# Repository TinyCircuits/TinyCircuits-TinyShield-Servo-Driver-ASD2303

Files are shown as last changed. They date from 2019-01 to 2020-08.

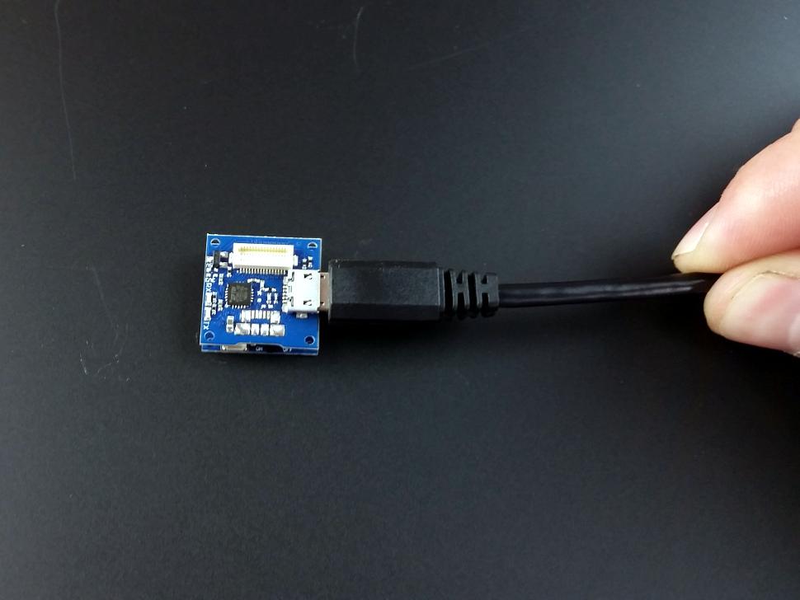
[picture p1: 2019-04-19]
images/ASD2303-Tutorial-Image-03.png

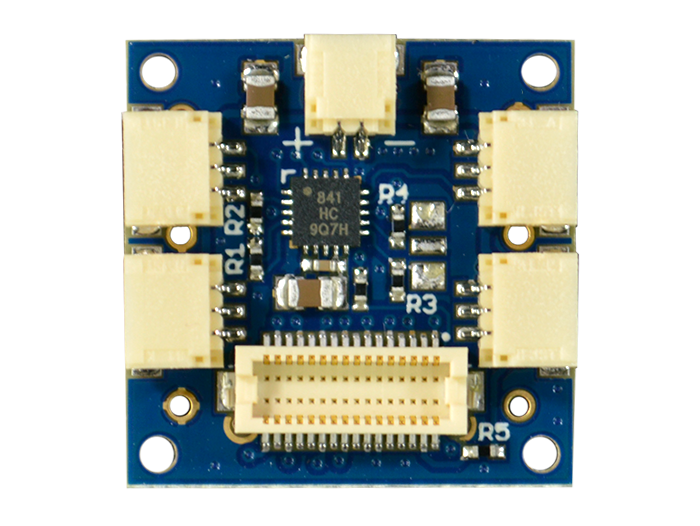
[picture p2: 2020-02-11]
images/ASD2303-R-Tutorial-Image-01.png

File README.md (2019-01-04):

# TinyCircuits-TinyShield-Servo-Driver-ASD2303
# ASD2303 Rev3

These are the design files for the TinyCircuits ASD2021 Rev 3 PCB.  This is a TinyShield (Square Version, 20mm x 20mm) that can drive up to four servos at a time.  

Format is in Cadsoft Eagle format - Eagle version 6.2 was used for the original design.

For more infomation on this, check out the product page at TinyCircuits.com:  https://tinycircuits.com/collections/motors/products/servo-tinyshield

# License:

Design by TinyCircuits.
All design files are released under the Creative Commons Attribution Share-Alike 3.0 License, see the following link for details: http://creativecommons.org/licenses/by-sa/3.0

All text above must be included in any redistribution or derived design

This project uses designs and concepts developed as part of the Arduino project and the LilyPad project.  The TinyCircuits design files themselves (schematics, PCB and libraries) are not directly derived from these works' design files and have been created new, however the concepts and basic architecture behind the TinyDuino and TinyLily products are derived and we thank the hard work of the organizations below for their contributions to open-source hardware:
  
Original Arduino Uno Design by Team Arduino

LilyPad Arduino Design by Leah Buechley and Sparkfun Electronics

Please support the open-source hardware community

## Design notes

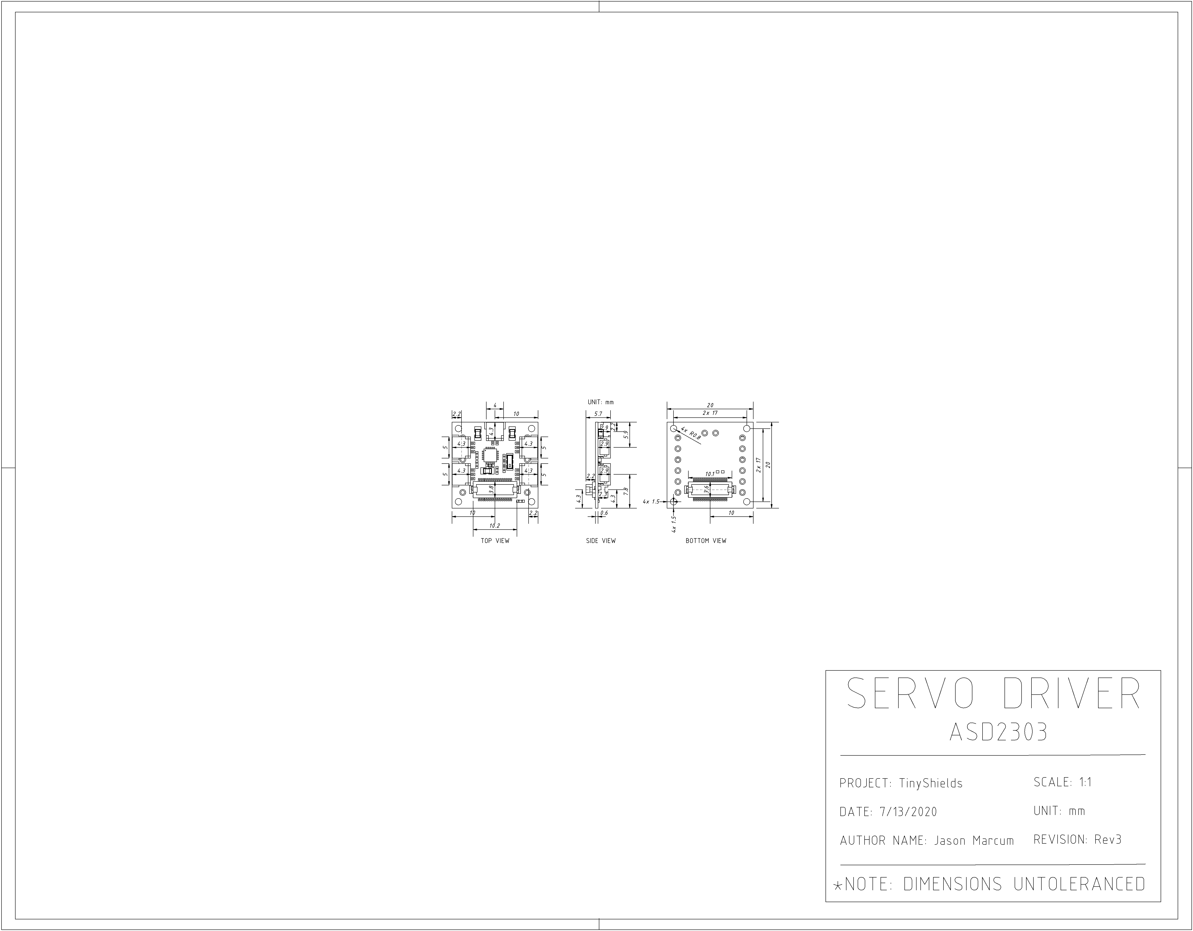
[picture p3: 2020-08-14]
cad/TinyShield_SERVO_ASD2303_REV3-DETAILED_DRAWING-PNG.png

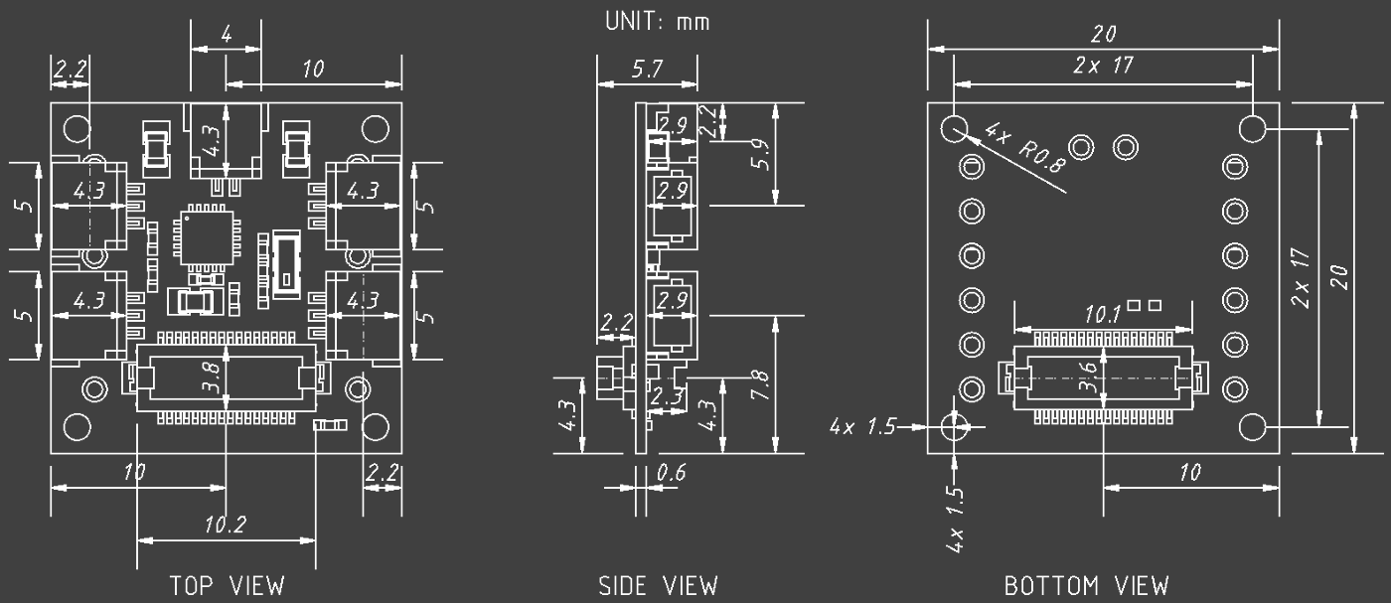
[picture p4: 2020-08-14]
cad/TinyShield_SERVO_ASD2303_REV3-DETAILED_DRAWING_COMPACT-PNG.png

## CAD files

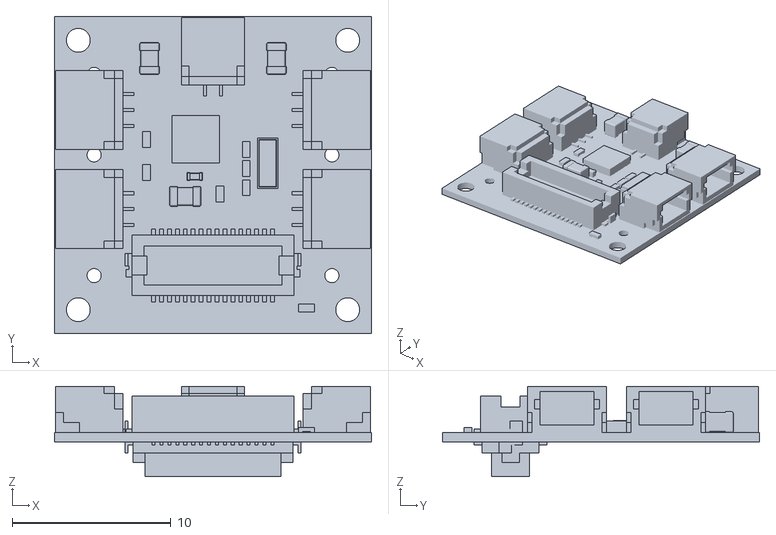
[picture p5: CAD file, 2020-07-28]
cad/TinyShield_SERVO_ASD2303_REV3-STL.stl
20.0 x 20.0 x 5.71

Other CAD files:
cad/TinyShield_SERVO_ASD2303_REV3-DETAILED_DRAWING-DXF.dxf

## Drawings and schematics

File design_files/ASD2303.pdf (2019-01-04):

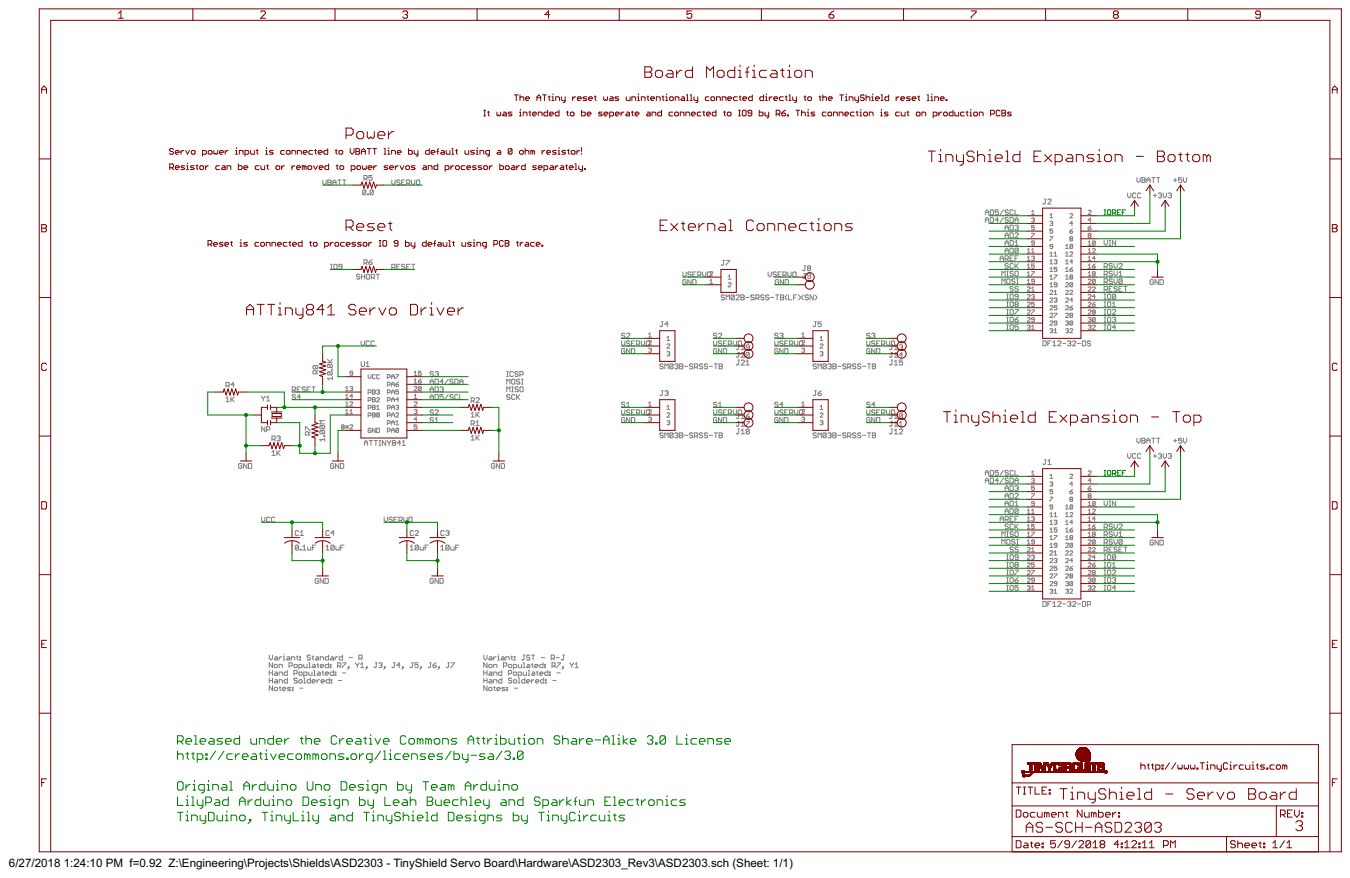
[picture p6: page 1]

6/27/2018 1:24:10 PM f=0.92 Z:\Engineering\Projects\Shields\ASD2303 - TinyShield Servo Board\Hardware\ASD2303_Rev3\ASD2303.sch (Sheet: 1/1)

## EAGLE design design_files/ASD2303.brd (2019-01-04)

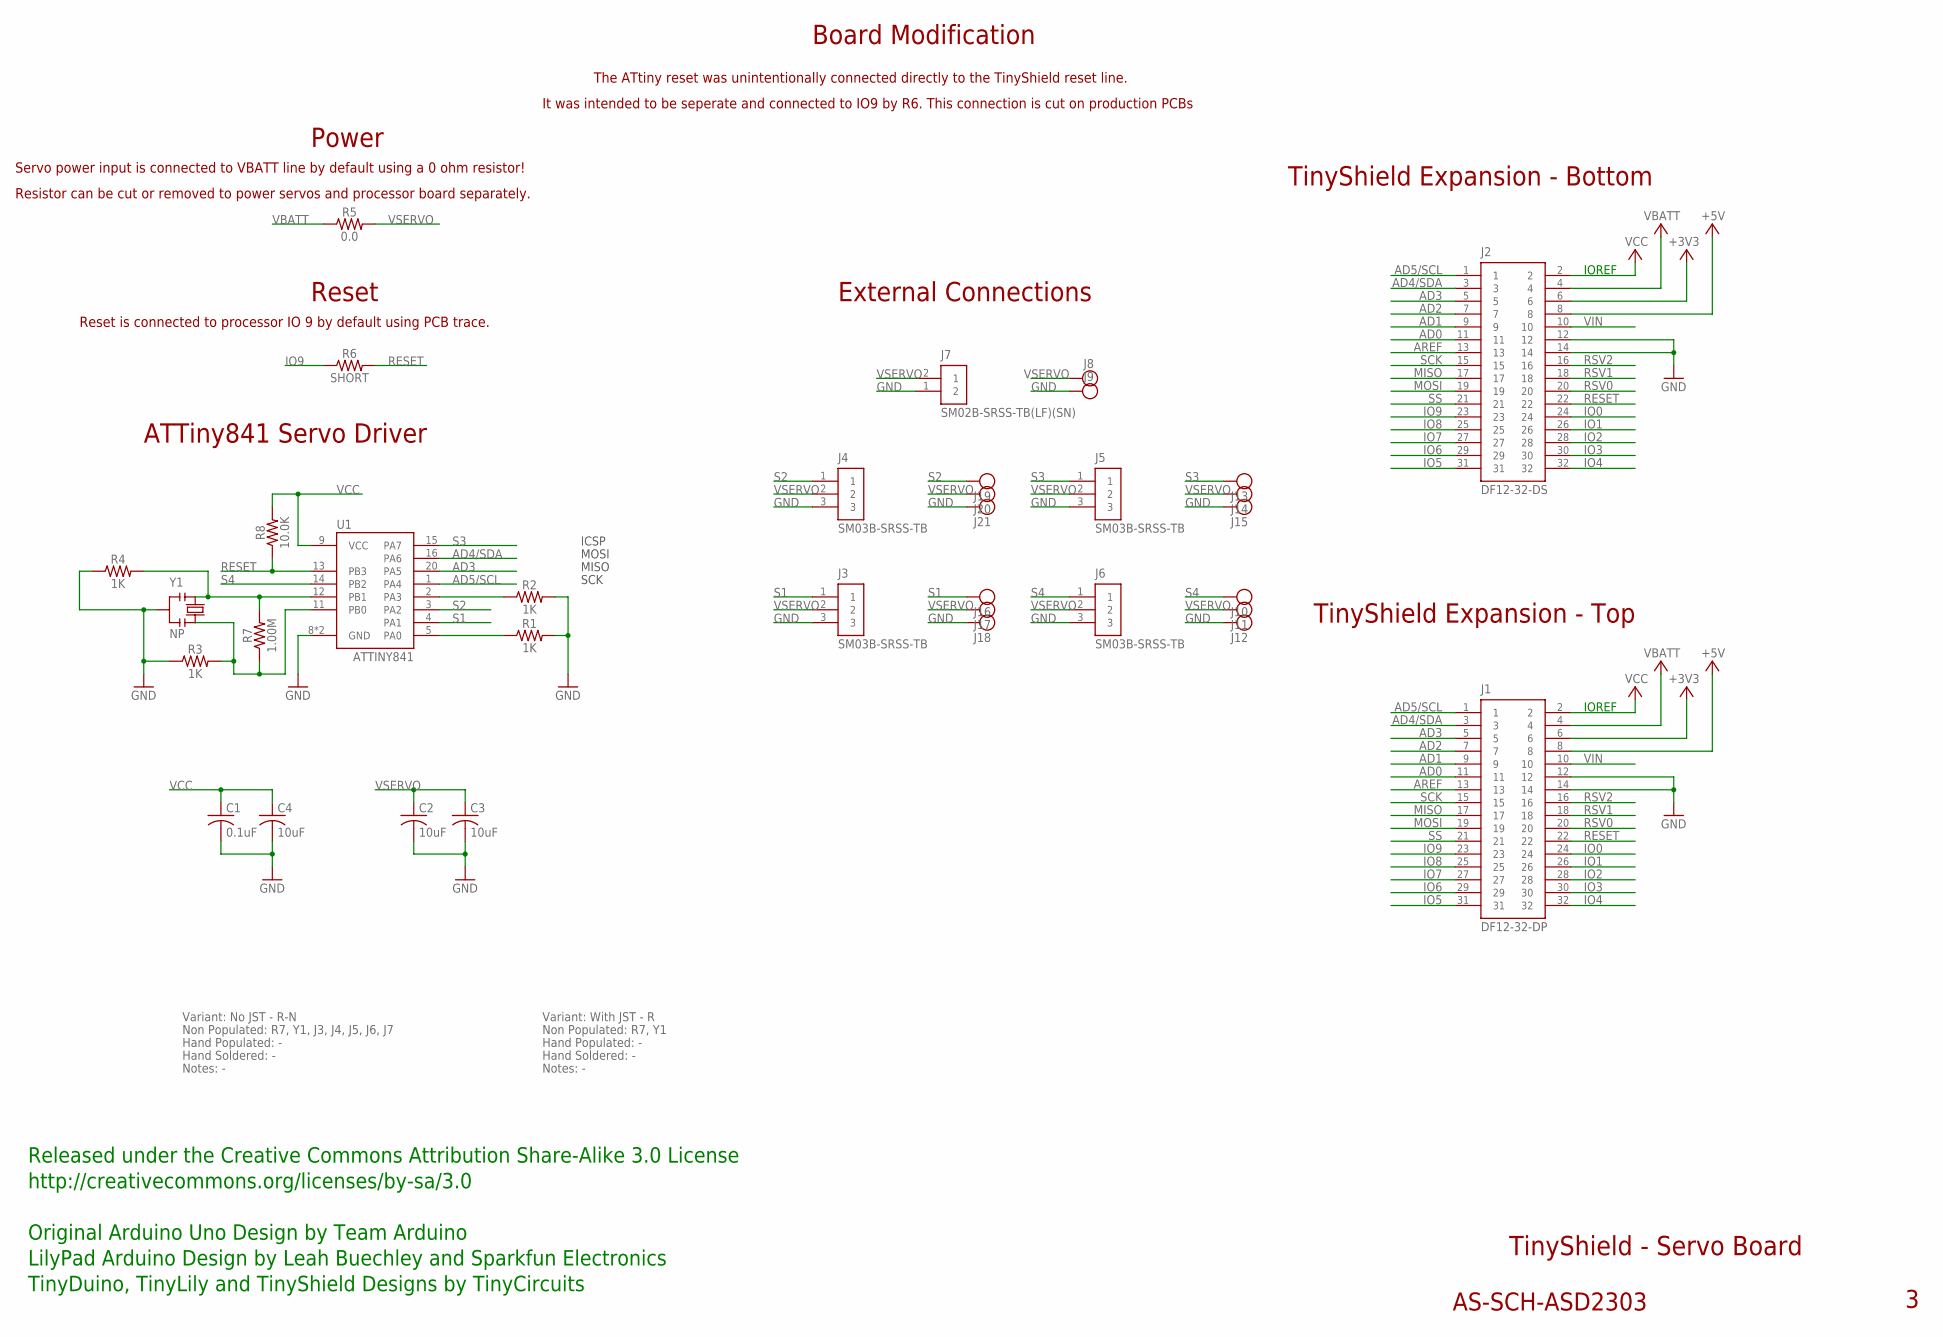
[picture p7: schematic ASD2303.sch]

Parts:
C1: 0.1uF; C0402
C2, C3, C4: 10uF; C0805
J1: DF12-32-DP; PARTNO AS-ITM-00015
J2: DF12-32-DS; PARTNO AS-ITM-00012
J3, J4, J5, J6: SM03B-SRSS-TB; JST_SH_3X1
J7: SM02B-SRSS-TB(LF)(SN); JST_SH_2X1
J8, J9, J10, J11, J12, J13, J14, J15, J16, J17, J18, J19, J20, J21: PIN_1X.1"1; 1X.1"_2
R1, R2, R3, R4: 1K; 0402; PARTNO AS-ITM-00003
R5: 0.0; 0402
R6: SHORT; 0402_SHORT
R7: 1.00M; 0402
R8: 10.0K; 0402
U1: ATTINY841; VQFN-20
Y1: NP; RESONATOR_SMALL; PARTNO AS-ITM-00027

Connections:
+3V3: J1.6, J2.6
+5V: J1.8, J2.8
AD0: J1.11, J2.11
AD1: J1.9, J2.9
AD2: J1.7, J2.7
AD3: J1.5, J2.5, U1.20 (PA5)
AD4/SDA: J1.3, J2.3, U1.16 (PA6)
AD5/SCL: J1.1, J2.1, U1.1 (PA4)
AREF: J1.13, J2.13
GND: C1.2, C2.2, C3.2, C4.2, J1.12, J1.14, J2.12, J2.14, J3.3, J4.3, J5.3, J6.3, J7.1 (2), J9.1, J12.1, J15.1, J18.1, J21.1, R1.2, R2.2, R3.1, R4.1, U1.8 (GND), U1.PAD (GND), Y1.2
IO0: J1.24, J2.24
IO1: J1.26, J2.26
IO2: J1.28, J2.28
IO3: J1.30, J2.30
IO4: J1.32, J2.32
IO5: J1.31, J2.31
IO6: J1.29, J2.29
IO7: J1.27, J2.27
IO8: J1.25, J2.25
IO9: J1.23, J2.23, R6.1
MISO: J1.17, J2.17
MOSI: J1.19, J2.19
unnamed: R4.2, R7.2, U1.12 (PB1), Y1.1
unnamed: R3.2, R7.1, U1.11 (PB0), Y1.3
unnamed: R2.1, U1.2 (PA3)
unnamed: R1.1, U1.5 (PA0)
RESET: J1.22, J2.22, R6.2, R8.1, U1.13 (PB3)
RSV0: J1.20, J2.20
RSV1: J1.18, J2.18
RSV2: J1.16, J2.16
S1: J3.1, J16.1, U1.4 (PA1)
S2: J4.1, J19.1, U1.3 (PA2)
S3: J5.1, J13.1, U1.15 (PA7)
S4: J6.1, J10.1, U1.14 (PB2)
SCK: J1.15, J2.15
SS: J1.21, J2.21
VBATT: J1.4, J2.4, R5.1
VCC: C1.1, C4.1, J1.2, J2.2, R8.2, U1.9 (VCC)
VIN: J1.10, J2.10
VSERVO: C2.1, C3.1, J3.2, J4.2, J5.2, J6.2, J7.2 (1), J8.1, J11.1, J14.1, J17.1, J20.1, R5.2

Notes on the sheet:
TinyShield Expansion - Bottom
TinyShield - Servo Board
AS-SCH-ASD2303
TinyShield Expansion - Top
IOREF
Released under the Creative Commons Attribution Share-Alike 3.0 License
http://creativecommons.org/licenses/by-sa/3.0
LilyPad Arduino Design by Leah Buechley and Sparkfun Electronics
TinyDuino, TinyLily and TinyShield Designs by TinyCircuits
Original Arduino Uno Design by Team Arduino
External Connections
ATTiny841 Servo Driver
MOSI
MISO
SCK
ICSP
Power
Resistor can be cut or removed to power servos and processor board separately.
Reset
Reset is connected to processor IO 9 by default using PCB trace.
Servo power input is connected to VBATT line by default using a 0 ohm resistor!
Board Modification
The ATtiny reset was unintentionally connected directly to the TinyShield reset line.
It was intended to be seperate and connected to IO9 by R6. This connection is cut on production PCBs
Variant: No JST - R-N
Non Populated: R7, Y1, J3, J4, J5, J6, J7
Hand Populated: -
Hand Soldered: -
Notes: -
Variant: With JST - R
Non Populated: R7, Y1

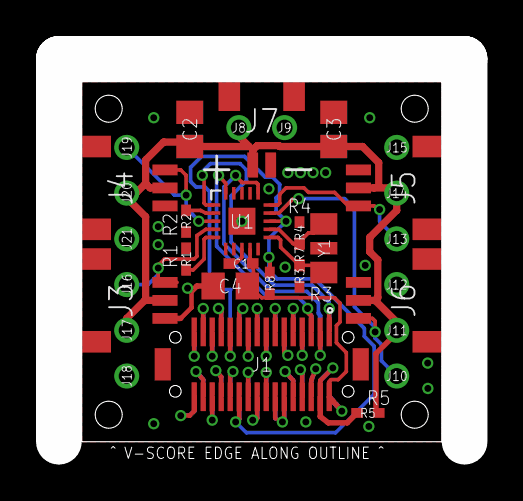
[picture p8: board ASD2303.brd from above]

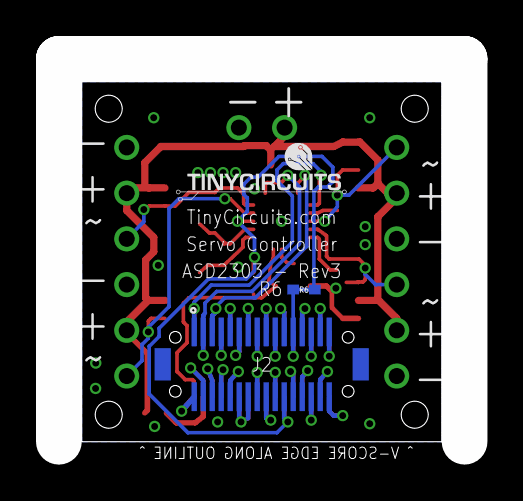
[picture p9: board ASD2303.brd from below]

Board: 2 copper layers, 20.0 x 20.0 mm, 36 parts (2 on the bottom side), 40 nets.

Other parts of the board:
U$1: DOCFIELD-TINYCIRCUITS-PCB

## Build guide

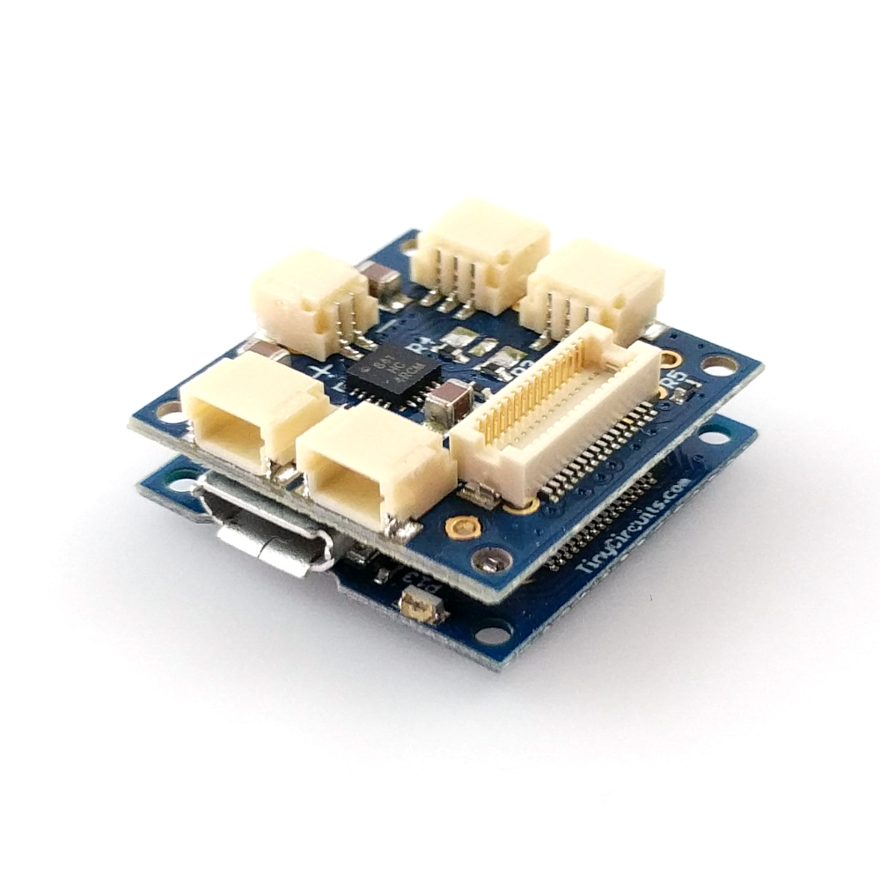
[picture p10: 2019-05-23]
images/ASD2303-R-Tutorial-Image-03.jpg

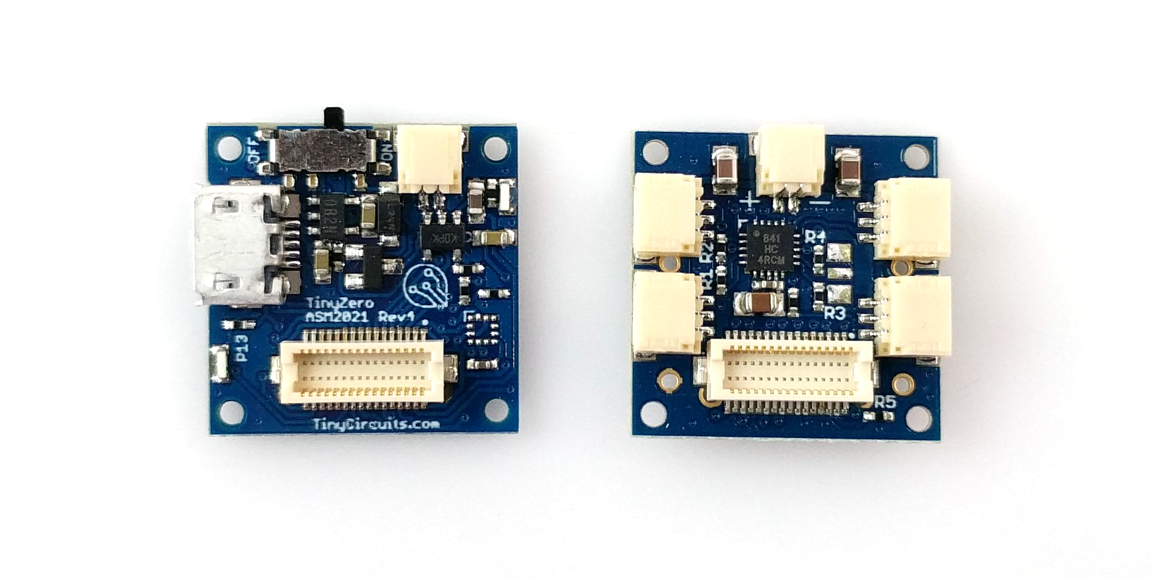
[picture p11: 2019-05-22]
images/ASD2303-R-Tutorial-Image-02.jpg

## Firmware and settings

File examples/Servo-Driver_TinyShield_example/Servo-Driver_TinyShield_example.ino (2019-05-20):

/*
  TinyCircuits Servo Driver TinyShield Example
  
  This example code shows basic usage of the ASD2303 servo Controller TinyShield.
  The library intance is created with the hardware address of the servo controller
  which can be changed by removed resistors R1-R3, allowing for up to 16 TinyShields.

  The board uses the ATtiny841 microcontroller and has direct register access-
  so just about any of the internal peripherals could be put to use.

  Written 11 July 2018
  By Ben Rose
  Modified 07 January 2019
  By Hunter Hykes

  https://TinyCircuits.com
*/

#include <Wire.h>
#include <ServoDriver.h>

ServoDriver servo(NO_R_REMOVED);//this value affects the I2C address, which can be changed by
                                //removing resistors R1-R3. Then the corresponding R1_REMOVED,
                                //R2_REMOVED, R1_R2_REMOVED, R1_R4_REMOVED and so on can be set.
                                //Default is NO_R_REMOVED

#if defined (ARDUINO_ARCH_AVR)
#define SerialMonitorInterface Serial
#elif defined(ARDUINO_ARCH_SAMD)
#define SerialMonitorInterface SerialUSB
#endif

void setup(){
  SerialMonitorInterface.begin(9600);
  Wire.begin();
  while(!SerialMonitorInterface)//This will block until the Serial Monitor is opened on TinyScreen+/TinyZero platform!
  pinMode(9, OUTPUT);//Pin 9 is the reset pin for the servo controller TinyShield
  digitalWrite(9, LOW);
  delay(10);
  digitalWrite(9, HIGH);
  delay(100);
  
  if(servo.begin(20000)){      //Set the period to 20000us or 20ms, correct for driving most servos
    SerialMonitorInterface.println("Motor driver not detected!");
    while(1);
  }
  //The failsafe turns off the PWM output if a command is not sent in a certain amount of time.
  //Failsafe is set in milliseconds- comment or set to 0 to disable
  servo.setFailsafe(1000);
}

void loop()
{
  for (int pos = 1000; pos <= 2000; pos += 30) {    // goes from 0 degrees to 180 degrees

    servo.setServo(1, pos);   // tell servo to go to position in variable 'pos'
    servo.setServo(2, pos);
    servo.setServo(3, pos);
    servo.setServo(4, pos);
    
    delay(20);                                  // wait 20ms for the servo to reach the position
  }
  for (int pos = 2000; pos >= 1000; pos -= 30) {    // goes from 180 degrees to 0 degrees
    servo.setServo(1, pos);   // tell servo to go to position in variable 'pos'
    servo.setServo(2, pos);
    servo.setServo(3, pos);
    servo.setServo(4, pos);
    
    delay(20);                                  // wait 20ms for the servo to reach the position
  }
}

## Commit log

2019-01-04 Update format
    [ASD2303.brd, ASD2303.sch]
2020-07-28 Add CAD data
    [TinyShield_SERVO_ASD2303_REV3-DETAILED_DRAWING-DXF.dxf, TinyShield_SERVO_ASD2303_REV3-STL.stl]
2020-08-14 Update CAD drawing
    [TinyShield_SERVO_ASD2303_REV3-DETAILED_DRAWING-DXF.dxf]
